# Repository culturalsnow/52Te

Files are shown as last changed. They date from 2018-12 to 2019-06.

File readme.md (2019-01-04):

# 52Te

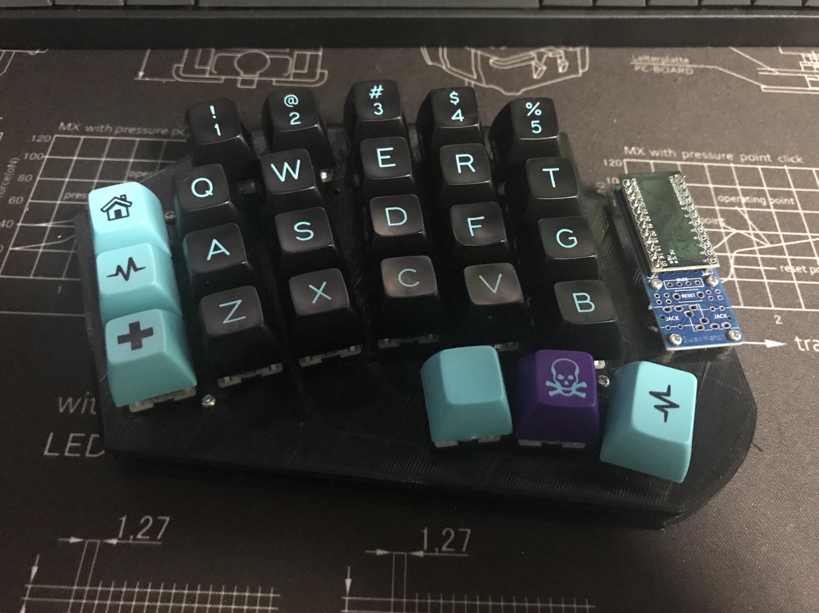
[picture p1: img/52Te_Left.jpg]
52Te Left Hand with SA Pulse


52Te is a split keyboard inspired by the NISSE keyboard created by Esrille.

https://www.esrille.com/keyboard/

The firmware is heavily based on Lily58 due to wiring and layout similarities.

https://github.com/kata0510/Lily58

Right now this is hand-wired with ProMicroSocket and BitBoard by swanmatch.

https://github.com/swanmatch/MxLEDBitPCB

May add a PCB for v2.0.

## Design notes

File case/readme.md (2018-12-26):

Plate and case stl files. 
One of the hands is upside down so make sure to flip it when you print.

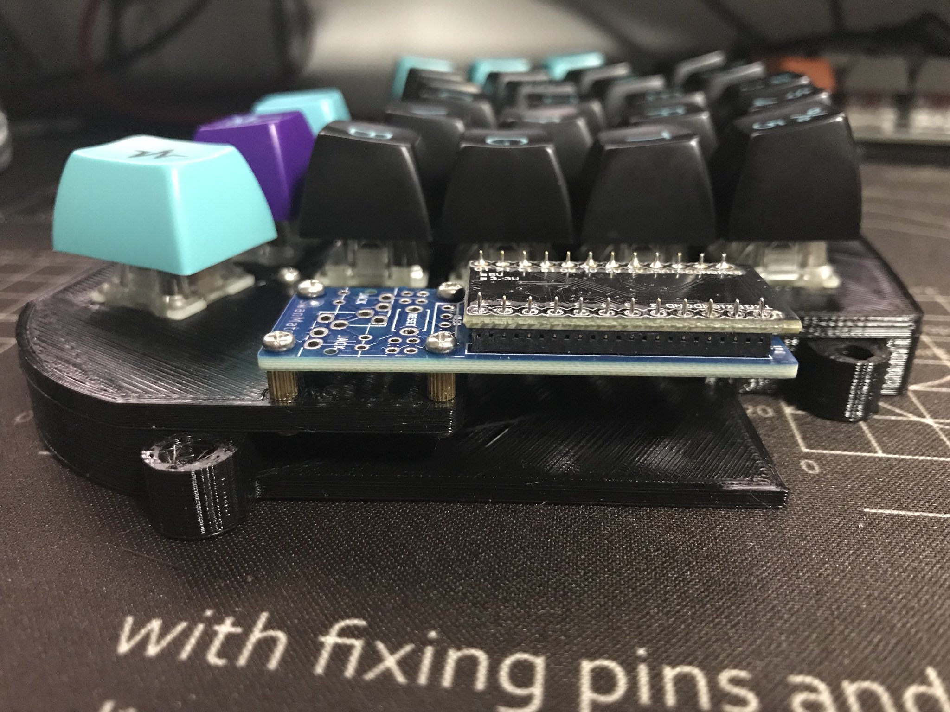
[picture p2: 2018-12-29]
img/caseSide.jpg

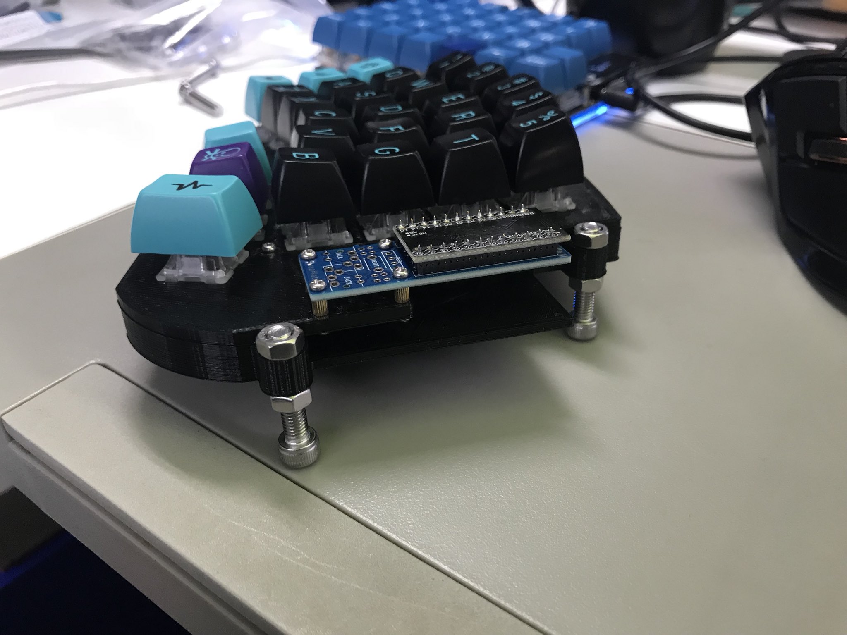
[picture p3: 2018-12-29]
img/tilting.jpg

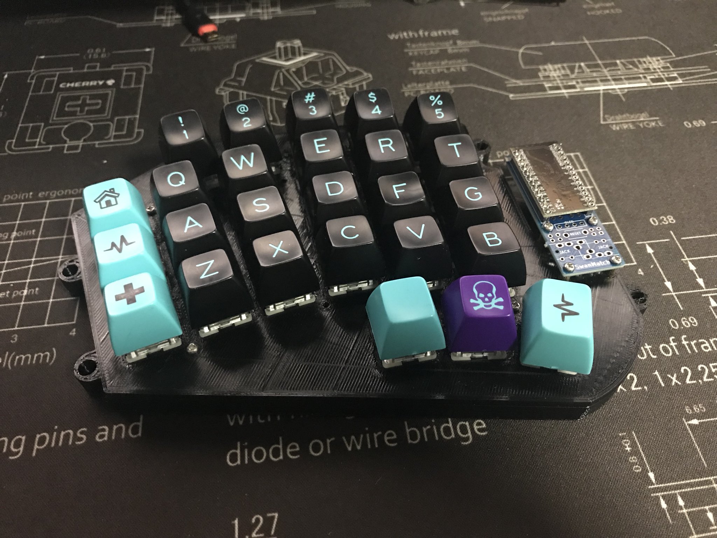
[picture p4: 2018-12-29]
img/withCase.jpg

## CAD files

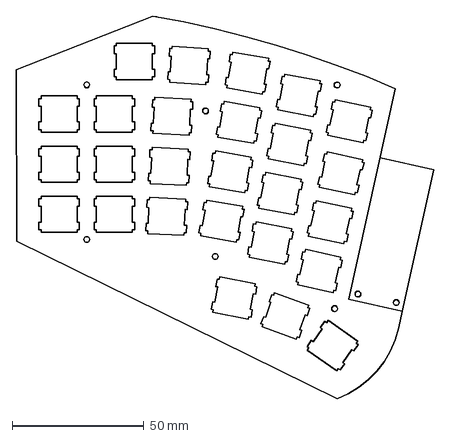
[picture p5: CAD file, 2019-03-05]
case/52Te_Top.dxf
158.7 x 145.6 mm

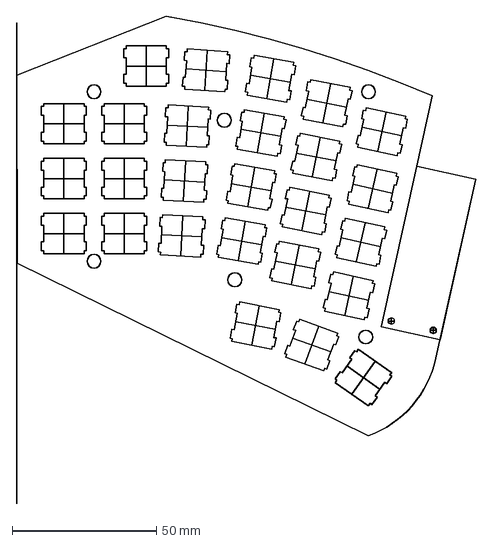
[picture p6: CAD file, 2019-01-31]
pcb/52Te_20190130_01.dxf
159.3 x 169.1 mm

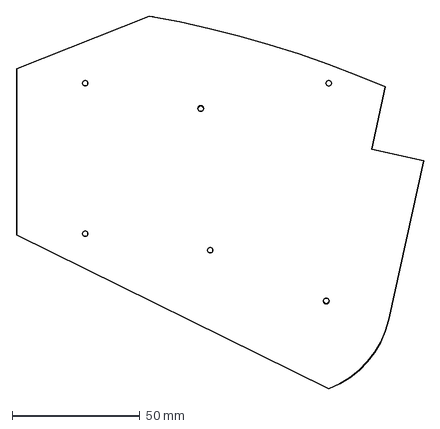
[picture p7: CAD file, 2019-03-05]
case/52Te_Bottom.dxf
159.3 x 145.6 mm

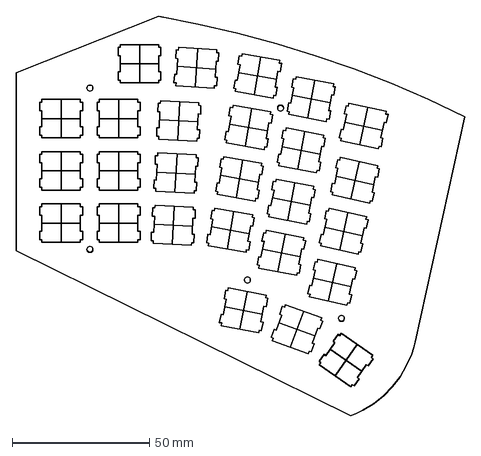
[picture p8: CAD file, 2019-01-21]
pcb/52TeLeftHandFromFusion.dxf
163.7 x 145.6 mm

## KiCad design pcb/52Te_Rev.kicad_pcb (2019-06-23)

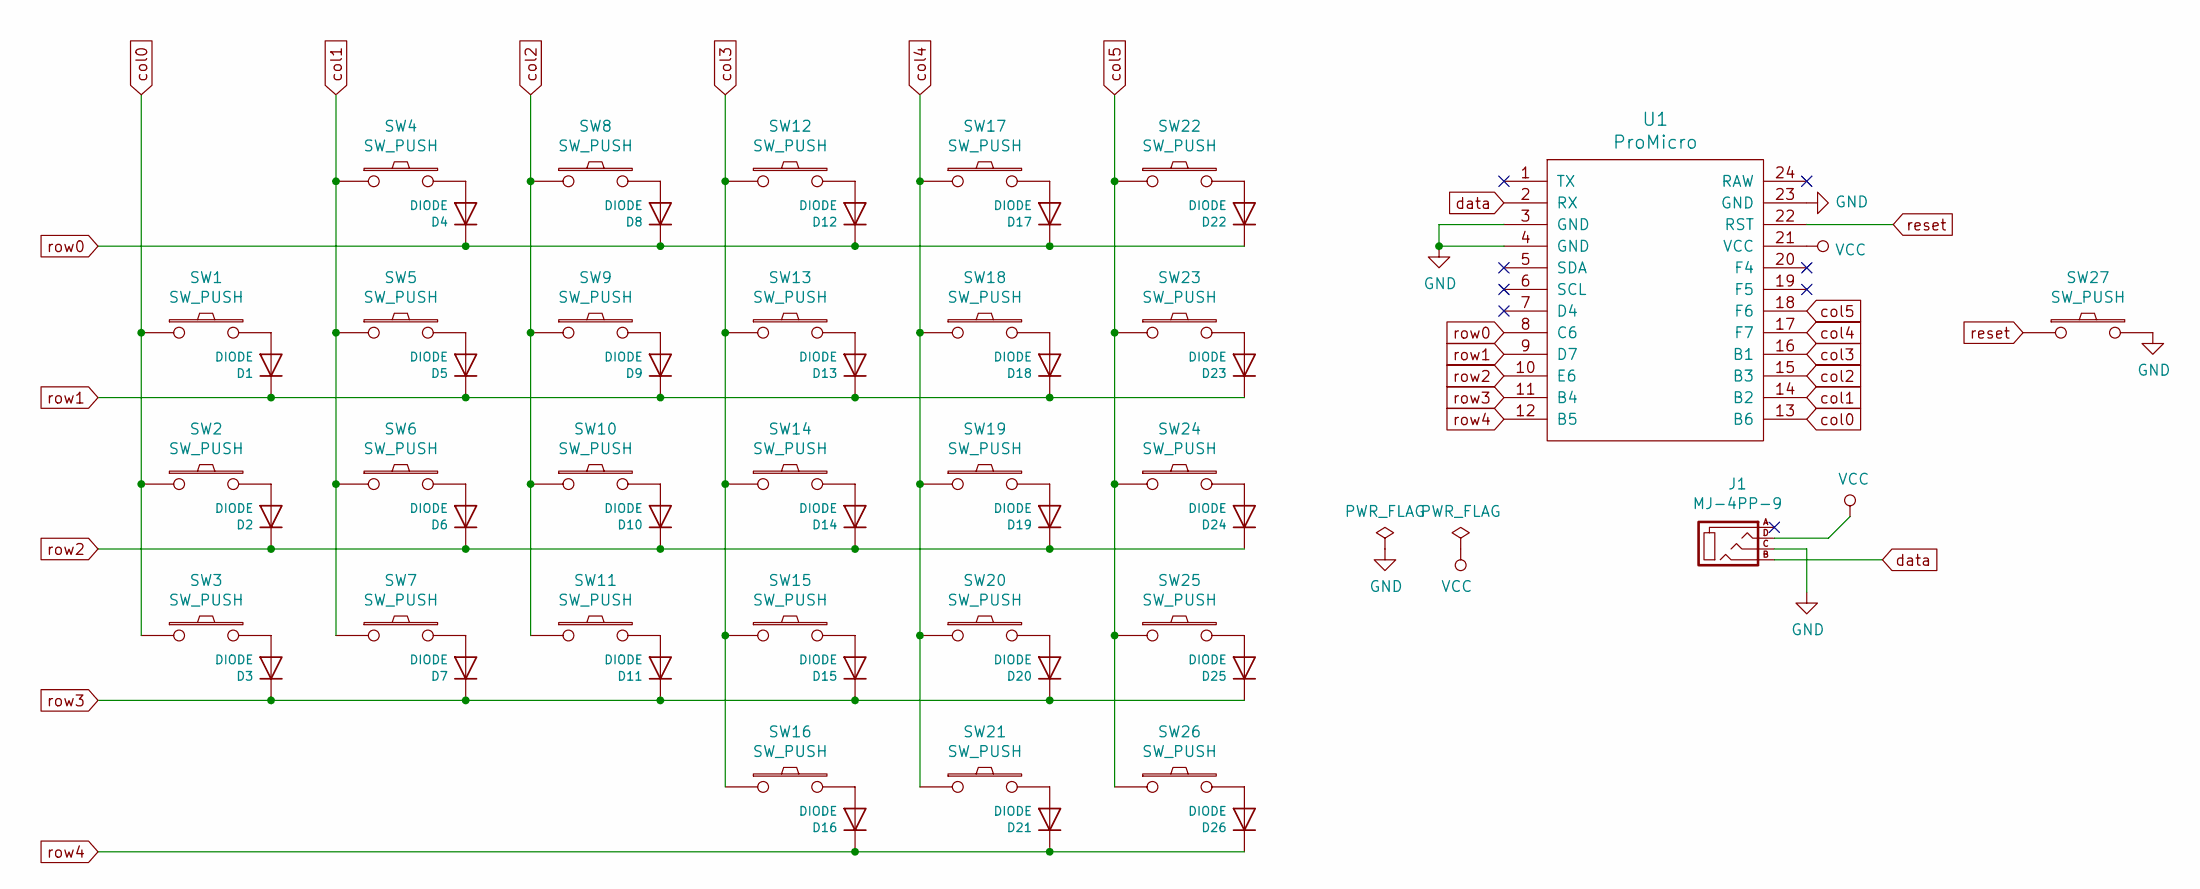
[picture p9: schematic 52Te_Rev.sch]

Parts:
D1, D2, D3, D4, D5, D6, D7, D8, D9, D10, D11, D12, D13, D14, D15, D16, D17, D18, D19, D20, D21, D22, D23, D24, D25, D26: DIODE; D3_TH_SMD
J1: MJ-4PP-9
SW1, SW2, SW3, SW4, SW5, SW6, SW7, SW8, SW9, SW10, SW11, SW12, SW13, SW14, SW15, SW16, SW17, SW18, SW19, SW20, SW21, SW22, SW23, SW24, SW25, SW26: SW_PUSH; CherryMX_Hotswap
SW27: SW_PUSH; ResetSW
U1: ProMicro; ProMicro_v2

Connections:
GND: J1.C, SW27.2, U1.3 (GND), U1.4 (GND), U1.23 (GND)
unnamed: D1.2 (A), SW1.2
unnamed: D2.2 (A), SW2.2
unnamed: D3.2 (A), SW3.2
unnamed: D4.2 (A), SW4.2
unnamed: D5.2 (A), SW5.2
unnamed: D6.2 (A), SW6.2
unnamed: D7.2 (A), SW7.2
unnamed: D8.2 (A), SW8.2
unnamed: D9.2 (A), SW9.2
unnamed: D10.2 (A), SW10.2
unnamed: D11.2 (A), SW11.2
unnamed: D12.2 (A), SW12.2
unnamed: D13.2 (A), SW13.2
unnamed: D14.2 (A), SW14.2
unnamed: D15.2 (A), SW15.2
unnamed: D16.2 (A), SW16.2
unnamed: D17.2 (A), SW17.2
unnamed: D18.2 (A), SW18.2
unnamed: D19.2 (A), SW19.2
unnamed: D20.2 (A), SW20.2
unnamed: D21.2 (A), SW21.2
unnamed: D22.2 (A), SW22.2
unnamed: D23.2 (A), SW23.2
unnamed: D24.2 (A), SW24.2
unnamed: D25.2 (A), SW25.2
unnamed: D26.2 (A), SW26.2
SCL: U1.6 (SCL)
SDA: U1.5 (SDA)
VCC: J1.D, U1.21 (VCC)
col0: SW1.1, SW2.1, SW3.1, U1.13 (B6)
col1: SW4.1, SW5.1, SW6.1, SW7.1, U1.14 (B2)
col2: SW8.1, SW9.1, SW10.1, SW11.1, U1.15 (B3)
col3: SW12.1, SW13.1, SW14.1, SW15.1, SW16.1, U1.16 (B1)
col4: SW17.1, SW18.1, SW19.1, SW20.1, SW21.1, U1.17 (F7)
col5: SW22.1, SW23.1, SW24.1, SW25.1, SW26.1, U1.18 (F6)
data: J1.B, U1.2 (RX)
reset: SW27.1, U1.22 (RST)
row0: D4.1 (K), D8.1 (K), D12.1 (K), D17.1 (K), D22.1 (K), U1.8 (C6)
row1: D1.1 (K), D5.1 (K), D9.1 (K), D13.1 (K), D18.1 (K), D23.1 (K), U1.9 (D7)
row2: D2.1 (K), D6.1 (K), D10.1 (K), D14.1 (K), D19.1 (K), D24.1 (K), U1.10 (E6)
row3: D3.1 (K), D7.1 (K), D11.1 (K), D15.1 (K), D20.1 (K), D25.1 (K), U1.11 (B4)
row4: D16.1 (K), D21.1 (K), D26.1 (K), U1.12 (B5)

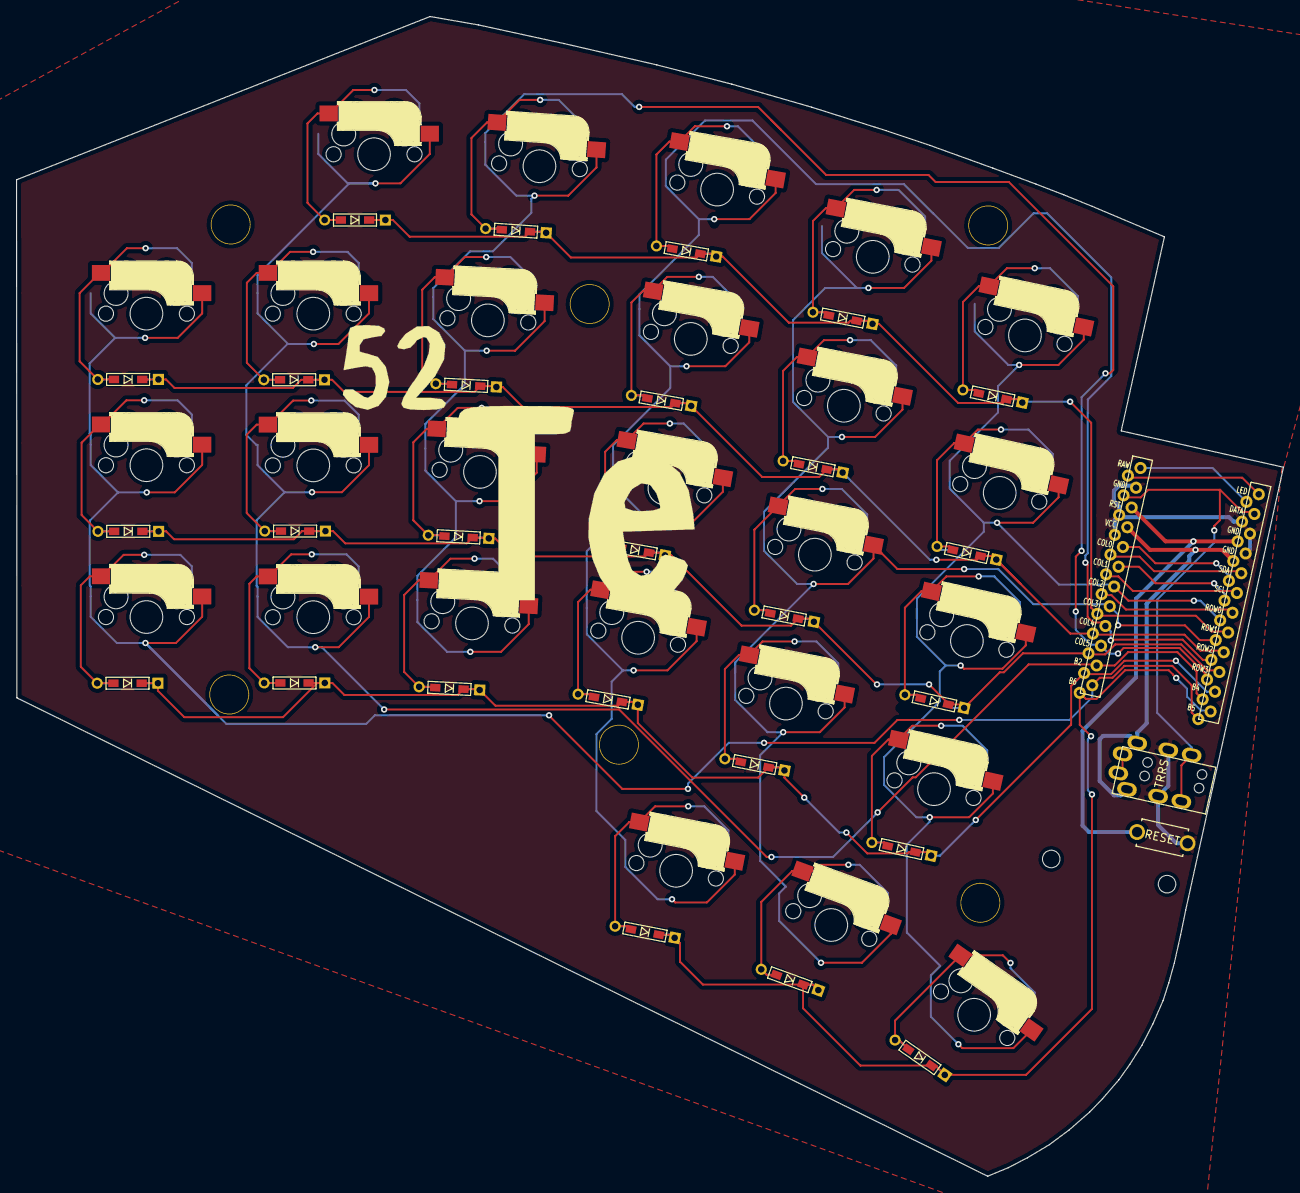
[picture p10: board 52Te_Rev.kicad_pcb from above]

Board: 2 copper layers, 159.1 x 145.6 mm, 61 parts (0 on the bottom side), 41 nets.

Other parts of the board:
Ref**: Val**; HOLE
Ref**#2, Ref**#3, Ref**#4, Ref**#5, Ref**#6: Val**; HOLE

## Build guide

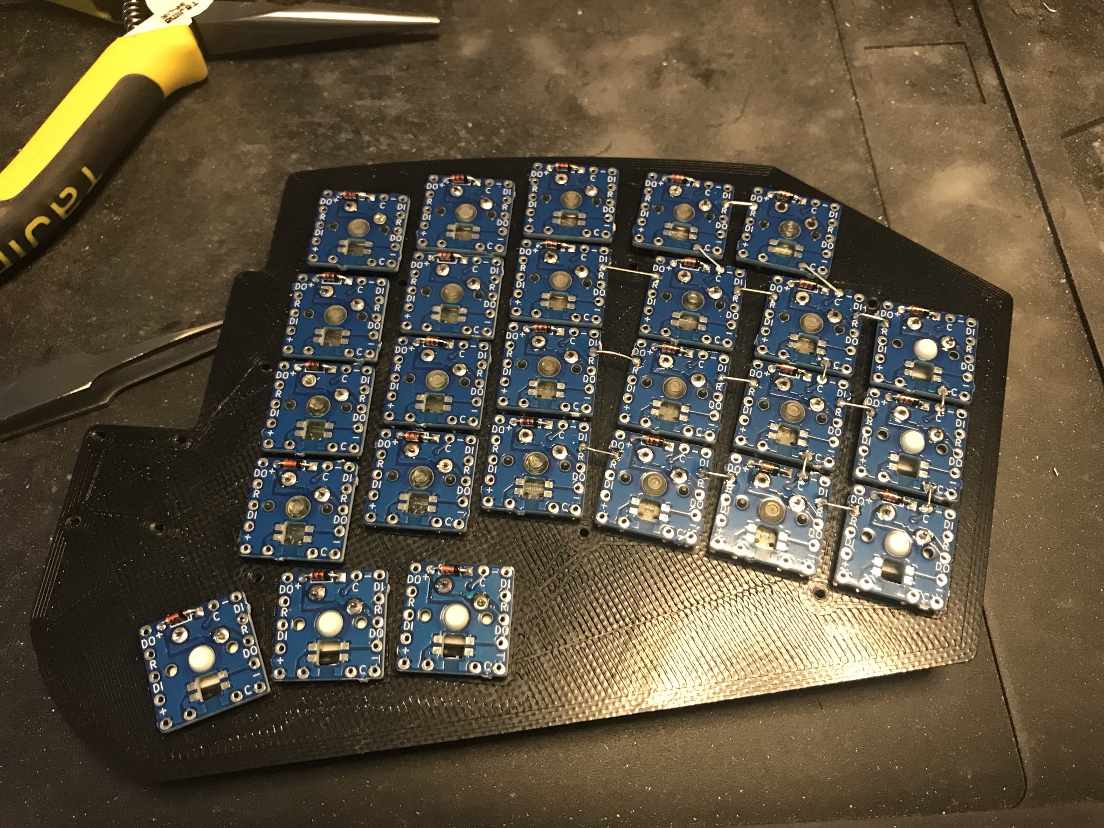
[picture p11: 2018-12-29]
img/handwiring.jpg

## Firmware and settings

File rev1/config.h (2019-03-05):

/*
Copyright 2012 Jun Wako <wakojun@gmail.com>
Copyright 2015 Jack Humbert
Copyright 2019 Bernard Shih

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
You should have received a copy of the GNU General Public License
along with this program.  If not, see <http://www.gnu.org/licenses/>.
*/

#pragma once

//#include QMK_KEYBOARD_CONFIG_H
#include "config_common.h"

/* USB Device descriptor parameter */
#define VENDOR_ID       0x0076
#define PRODUCT_ID      0x0052
#define DEVICE_VER      0x0100
#define MANUFACTURER    EMPTYSTRING
#define PRODUCT         52Te
#define DESCRIPTION     A split keyboard with 52 keys, inspired by the NISSE keyboard.

/* key matrix size */
// Rows are doubled-up
#define MATRIX_ROWS 10
#define MATRIX_COLS 6

// wiring of each half
#define MATRIX_ROW_PINS { C6, D7, E6, B4, B5 }
#define MATRIX_COL_PINS { B6, B2, B3, B1, F7, F6 }

#define CATERINA_BOOTLOADER

/* define tapping term */
#define TAPPING_TERM 300

#define MASTER_LEFT

/* define if matrix has ghost */
//#define MATRIX_HAS_GHOST

/* Set 0 if debouncing isn't needed */
#define DEBOUNCING_DELAY 5

/* Mechanical locking support. Use KC_LCAP, KC_LNUM or KC_LSCR instead in keymap */
#define LOCKING_SUPPORT_ENABLE
/* Locking resynchronize hack */
#define LOCKING_RESYNC_ENABLE

/* key combination for command */
#define IS_COMMAND() ( \
    keyboard_report->mods == (MOD_BIT(KC_LSHIFT) | MOD_BIT(KC_RSHIFT)) \
)

/* ws2812 RGB LED */
//#define RGB_DI_PIN D3
//#define RGBLIGHT_TIMER
//#define RGBLED_NUM 14    // Number of LEDs
//#define ws2812_PORTREG  PORTD
//#define ws2812_DDRREG   DDRD

/*
 * Feature disable options
 *  These options are also useful to firmware size reduction.
 */

/* disable debug print */
// #define NO_DEBUG

/* disable print */
// #define NO_PRINT

/* disable action features */
//#define NO_ACTION_LAYER
//#define NO_ACTION_TAPPING
//#define NO_ACTION_ONESHOT
//#define NO_ACTION_MACRO
//#define NO_ACTION_FUNCTION

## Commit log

2019-01-21 added PCB file for left hand
    [52Te_Lefthand.kicad_pcb, 52Te_Lefthand.sch]
2019-01-21 plate bulder dxf
    [52TeLeftHand.dxf]
2019-01-21 EOD 20190121 at work
    [52Te_Lefthand.sch]
2019-01-21 20190122 placement
    [52TeLeftHand.dxf, 52TeLeftHandFromFusion.dxf, 52Te_Lefthand.sch]
2019-01-22 first draft pcb lefthand
    [52Te_Lefthand.kicad_pcb, 52Te_Lefthand.sch]
2019-01-24 new pcb reversible design
    [52Te_Lefthand.kicad_pcb, 52Te_Lefthand.sch, 52Te_Rev.kicad_pcb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]
2019-01-24 v1.0 final 20190124
    [52Te_Rev-B.Cu.gbr, 52Te_Rev-B.Mask.gbr, 52Te_Rev-B.SilkS.gbr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]
2019-01-28 firmware update for pcb
2019-01-31 redo pcb
    [52Te_20190130_01.dxf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]
2019-02-01 latest 20190201
    [52Te_Rev.kicad_pcb]
2019-02-13 20190213 added logos
    [52Te_Rev.kicad_pcb]
2019-02-18 gerber uploaded
    [52Te_Rev-B.Cu.gbr, 52Te_Rev-B.Mask.gbr, 52Te_Rev-B.SilkS.gbr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]
2019-03-05 fixed PCB TRRS jack connection
    [52Te_Rev.kicad_pcb, 52Te_Rev.sch]
2019-03-05 new gerber file
    [52Te_Rev-B.Cu.gbr, 52Te_Rev-B.Mask.gbr, 52Te_Rev-B.SilkS.gbr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]
2019-03-05 added screw holes back, new gerber
    [52Te_Bottom.dxf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]
2019-03-05 added logos
    [52Te_Rev-B.Cu.gbr, 52Te_Rev-B.Mask.gbr, 52Te_Rev-B.SilkS.gbr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]
2019-03-05 removed OLED footprints
    [52Te_Rev-B.Cu.gbr, 52Te_Rev-B.Mask.gbr, 52Te_Rev-B.SilkS.gbr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]
2019-03-06 removed some files
    [CaseLeft.stl, CaseRight.stl, Plate.stl]
2019-03-12 added holes and redid routing around trrs/reset
    [52Te_Rev-B.Cu.gbr, 52Te_Rev-B.Mask.gbr, 52Te_Rev-B.SilkS.gbr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]

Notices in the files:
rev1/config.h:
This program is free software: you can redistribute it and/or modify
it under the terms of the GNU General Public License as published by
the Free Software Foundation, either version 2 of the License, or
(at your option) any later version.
